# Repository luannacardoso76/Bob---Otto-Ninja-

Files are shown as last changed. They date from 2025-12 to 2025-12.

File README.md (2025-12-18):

# Bob---Otto-Ninja-
Projeto acadêmico do Robô Otto Ninja Humanoide “Bob”, desenvolvido na disciplina Informática Aplicada à Engenharia. O trabalho envolve modelagem com Redes de Petri, impressão 3D, montagem mecânica, integração eletrônica com Arduino Nano e programação embarcada para controle de movimentos e sensores.

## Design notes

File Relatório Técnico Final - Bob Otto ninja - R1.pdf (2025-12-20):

UNIVERSIDADE DO ESTADO DA BAHIA - UNEB DEPARTAMENTO DE CIÊNCIAS EXATAS E DA TERRA I COLEGIADO DE ENGENHARIA DE PRODUÇÃO CIVIL

FELIPE DIAS CAVALCANTE DO NASCIMENTO LUANNA CARDOSO DOS ANJOS

RELATÓRIO TÉCNICO – DESENVOLVIMENTO DO ROBÔ OTTO NINJA HUMANOIDE

SALVADOR - BAHIA
2025

FELIPE DIAS CAVALCANTE DO NASCIMENTO LUANNA CARDOSO DOS ANJOS

RELATÓRIO TÉCNICO – DESENVOLVIMENTO DO ROBÔ OTTO NINJA HUMANOIDE

Relatório Técnico apresentado como critério de avaliação da disciplina Informática Aplicada a Engenharia do curso de Engenharia de Produção Civil da Universidade do Estado da Bahia - UNEB.

Prof. Orientador: Robson Marinho da Silva

SALVADOR - BAHIA
2025

### 1. INTRODUÇÃO

O presente relatório técnico apresenta o desenvolvimento do Robô Otto DIY Ninja Humanoide, denominado “Bob”, realizado no âmbito da disciplina Informática Aplicada à Engenharia, do curso de Engenharia de Produção Civil da Universidade do Estado da Bahia (UNEB). O projeto teve como objetivo integrar conhecimentos de programação, eletrônica básica, modelagem computacional, impressão 3D e gerenciamento de projetos, por meio da prototipagem de um sistema mecatrônico.
O desenvolvimento iniciou-se com a modelagem do comportamento do robô utilizando Redes de Petri simples e compostas, que possibilitaram o planejamento lógico das ações e a definição da arquitetura de controle do sistema. Em seguida, foram realizadas a definição da lista de materiais, a impressão 3D das peças estruturais e a montagem mecânica e elétrica, etapa que demandou ajustes iterativos e adaptações em função das características dos componentes disponíveis.
Por fim, efetuou-se a programação e integração dos subsistemas, envolvendo o controle dos servomotores, a leitura do sensor ultrassônico e a utilização do display para interação visual. Durante essa fase, desafios técnicos, como a substituição de uma placa controladora defeituosa, contribuíram para o desenvolvimento de competências relacionadas à organização, diagnóstico técnico e resolução de problemas, consolidando os objetivos propostos pela disciplina.
2. MODELAGEM DO ROBÔ UTILIZANDO REDES DE PETRI

A primeira etapa do projeto consistiu no desenvolvimento de uma Rede de Petri simples, que evoluiu para uma Rede de Petri composta (colorida), utilizando os softwares HPSIM e CPN Tools. Essas modelagens tiveram como finalidade representar, de forma lógica e estruturada, o comportamento e os movimentos principais do robô.

### 2.1. Rede de Petri Simples

A Rede de Petri simples permitiu mapear:
- Os estados fundamentais do robô (ligado, executando, repouso);
- As transições referentes a movimentos básicos (andar, girar, acenar, mostrar expressões);
- A lógica de alternância entre ações;
- O mecanismo de exclusão mútua (lugar busy), garantindo que apenas uma ação fosse executada por vez.
Esta modelagem facilitou a identificação de cenários de teste e a previsão de situações de bloqueio (deadlock) e condições de corrida, orientando ajustes posteriores no projeto físico e no código de controle.

### 2.2. Rede de Petri Composta (Colorida)

A etapa seguinte consistiu na construção de uma Rede de Petri colorida, que representa tokens com informações (cores) como tipo de comando, parâmetros e estados. A modelagem colorida possibilitou:

- Compactar várias situações (ex.: diferentes comandos) em uma mesma estrutura de transição;
- Simular cenários com parâmetros (velocidade, duração, prioridade);
- Verificar lógica de interação entre subsistemas (pernas, rodas, braços, display e sensor de obstáculo).
A modelagem por Redes de Petri, tanto simples quanto colorida, foi relevante para antecipar o comportamento do robô, definindo critérios de sucesso para a implementação e testes.
3. LISTA DE MATERIAIS DO PROJETO

Após a fase de modelagem, elaborou-se a lista de materiais necessária para a montagem do protótipo. A lista incluiu itens eletrônicos, mecânicos e de fixação, bem como as peças a serem impressas em 3D. Entre os componentes principais destacam-se:
- 5 Servomotores de 180°;
- 2 Servomotores de 360°;
- 1 Sensor ultrassônico HC-SR04;
- 1 Tela OLED 0.96" I2C 128x64 (display);
- 1 Placa controladora Shield associada ao Arduino Nano;
- 1 Bateria recarregável de 7,4V;
- Cabos Dupont, conectores e parafusos;
- 2 Capacitores Ketuo 16V;
- Peças estruturais impressas em 3D (lista detalhada na Seção 4).
Ressalta-se que alguns componentes diferiram das especificações originais do projeto Otto DIY, em função da disponibilidade de materiais fornecidos, exigindo adaptações durante o desenvolvimento.

### 4. IMPRESSÃO 3D DAS PEÇAS ESTRUTURAIS

A estrutura mecânica do robô foi produzida por meio de impressão 3D, processo que demandou diversas iterações até a obtenção de peças com qualidade dimensional e acabamento adequados.

### 4.1. Peças Impressas

Foram impressas as seguintes peças:
- Tampa preta para cabeça;
- Base da cabeça;
- Espada azul;
- 2 × Ombros;
- 2 × Braços;
- Tornozelo esquerdo;
- Tornozelo direito;
- Base preta;
- 2 × Pés;
- Parte inferior interna;

- Pernas;
- Tampa inicial;
- Tampa ultrassônica para o sensor;
- Faixa azul.

### 4.2. Processo e ajustes

A impressão das peças durou várias semanas. Algumas peças foram reimpressas devido a falhas de acabamento ou dimensionais. Foi necessário ajustar modelos no software Autodesk Fusion 360, entre eles:
- Redimensionamento e reposicionamento da abertura frontal do corpo para acomodar a matriz de LEDs (a matriz adquirida apresentou dimensões diferentes do modelo original);
- Correções de encaixe nas articulações (ombros e tornozelos);
- Inclusão de características estéticas e identificação (nome dos integrantes, nome do orientador, ano e mês), que foram incorporadas ao modelo final.

### 5. MONTAGEM MECÂNICA E INSTALAÇÃO DOS COMPONENTES

Finalizadas as impressões e os ajustes, procedeu-se à montagem mecânica e à instalação dos atuadores e sensores.

### 5.1. Instalação de servos

Os servos foram instalados conforme a arquitetura prevista:
- Pernas: em cada perna foi instalado um servo de 180° e um servo de 360°;
- Braços: um servo de 360º por braço;
- Cabeça: um servo de 360° (para movimentação da cabeça) e sensor ultrassônico HC-SR04 montado na tampa frontal;
- Posições físicas dos servos e referências de portas na shield.

### 5.2. Bateria e alimentação

A bateria utilizada foi do tipo: Bateria recarregável 7,4V, instalada na cavidade do corpo. A alimentação é gerenciada por um capacitor conforme especificações da lista de materiais, garantindo 5V para os servos e 3.3V/5V para a placa controladora conforme necessidade.

### 5.3. Placa controladora e conexões

O robô utilizou a combinação Shield e Arduino Nano.

### 5.4. Conexões e Cabeamento

Os componentes foram conectados às portas apropriadas da Shield:
- Servos das pernas
o Direita → posição: 3
o Esquerda → posição: 2
- Servos dos pés
o Direita → posição: 5
o Esquerda → posição: 4

- Servos dos braços
o Direita → posição: 7
o Esquerda → posição: 6
- Servo da cabeça → posição: 10
- Sensor ultrassônico
o Saída: VCC → Cabo: vermelho → posição: 9V o Saída: TRIG → Cabo: preto → posição: 8S
o Saída: ECHO → Cabo: branco → posição: 9S o Saída: GND → Cabo: cinza → posição: 8G
- Display (tela OLED)
o Saída: GND → Cabo: verde → posição: A4G o Saída: VDD → Cabo: amarelo → posição: A4V o Saída: SCK → Cabo: salmão → posição: A5S o Saída: SDA → Cabo: vermelho → posição: A4S
- Bateria
o Cabo: vermelho → posição: VIN
o Cabo: preto → posição: GND
- Capacitor
o 5/Cabo: azul → posição: 0G
o Cabo: amarelo → posição: 0V

### 6. PROGRAMAÇÃO E INTEGRAÇÃO

Com os componentes integrados, iniciou-se a preparação do ambiente de desenvolvimento e a configuração da placa no Arduino IDE. As etapas realizadas até o ponto atual incluem:
- Instalação de bibliotecas para servos, sensor ultrassônico, e para o controlador da matriz;
- Configuração da placa e da porta serial;
- Planejamento da arquitetura de software baseada nas Redes de Petri desenvolvidas. Nessa etapa, foi identificado que a placa Arduino Nano inicialmente utilizada apresentava indícios de falha, possivelmente decorrente de dano físico no circuito, conforme evidenciado pelo furo observado na placa (Figura 1). Tal condição impossibilitou a comunicação adequada entre o computador e o microcontrolador, inviabilizando o carregamento do firmware e a execução dos testes iniciais.

Figura 1 - Arduino Nano com furo sugerindo placa queimada

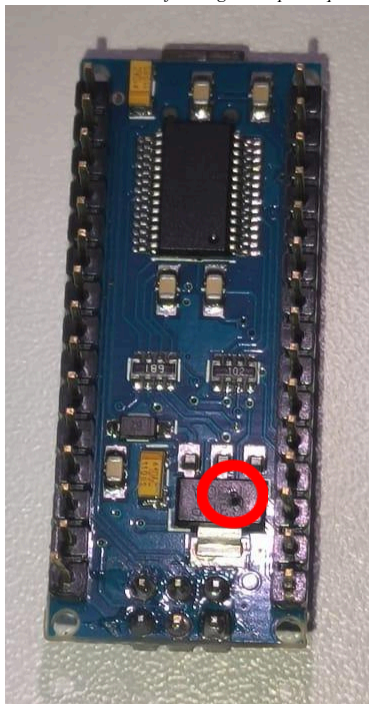
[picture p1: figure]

Fonte: O autor (2025)
Diante desse diagnóstico, tornou-se necessária a aquisição de um novo Arduino Nano, permitindo a retomada das atividades de programação. Após a substituição da placa, foi possível configurar corretamente o ambiente no Arduino IDE, estabelecer comunicação serial e iniciar a implementação do código responsável pelo controle dos servomotores, leitura do sensor ultrassônico e acionamento do display.

### 7. GERENCIAMENTO DO PROJETO

O acompanhamento e a organização do projeto foram realizados por meio da ferramenta Trello, utilizada para:
- Criação de cartões de tarefas (impressão 3D, montagem, programação, testes);
- Atribuição de responsabilidades entre os integrantes;
- Registro de progresso e impedimentos;
- Armazenamento de registros de iteração (reimpressões, ajustes de modelo) e fotos das peças.
O uso do Trello permitiu manter rastreabilidade das atividades, priorizar tarefas e documentar decisões durante todo o desenvolvimento.

### 8. DOCUMENTAÇÃO DO PROJETO

A documentação do projeto foi elaborada de forma contínua ao longo de todas as etapas de desenvolvimento do Robô Otto Ninja Humanoide. Foram produzidos registros técnicos que contemplam a modelagem do sistema por meio de Redes de Petri, a lista de materiais, os arquivos de modelagem e impressão 3D, registros fotográficos do processo de fabricação e montagem, esquemas de ligação elétrica e versões sucessivas do código-fonte desenvolvido. Além disso, foi criado um repositório no GitHub (https://github.com/luannacardoso76/Bob---Otto-Ninja-.git) com a finalidade de centralizar e preservar todos os arquivos digitais do projeto, incluindo códigos de programação, diagramas, modelos tridimensionais e documentos textuais. Essa prática contribuiu para a organização, rastreabilidade e versionamento das informações, possibilitando maior transparência, reprodutibilidade do projeto e facilidade para futuras melhorias. O uso dessa plataforma também está alinhado às boas práticas de engenharia e desenvolvimento tecnológico, especialmente no que se refere ao trabalho colaborativo e à gestão de versões.

### 9. CONSIDERAÇÕES FINAIS

O desenvolvimento do Robô Otto DIY Ninja Humanoide proporcionou aos integrantes uma experiência prática e integrada, envolvendo conceitos de programação, eletrônica, modelagem computacional, impressão 3D e gerenciamento de projetos. A utilização das Redes de Petri mostrou-se uma ferramenta eficiente para o planejamento lógico do comportamento do robô, auxiliando na organização das ações e na redução de falhas durante a integração entre os subsistemas.
As etapas de impressão 3D e montagem mecânica evidenciaram a importância do processo iterativo de prototipagem, uma vez que ajustes sucessivos foram necessários até alcançar um resultado funcional e esteticamente satisfatório. No âmbito da programação, a identificação e substituição da placa Arduino Nano defeituosa representaram um desafio relevante, reforçando a necessidade de diagnóstico técnico, tomada de decisão e adaptação frente a imprevistos, situações comuns em projetos de engenharia.
De modo geral, os objetivos propostos pela disciplina foram plenamente atingidos, permitindo a consolidação dos conhecimentos teóricos por meio de sua aplicação prática. O projeto demonstrou o potencial do Robô Otto como plataforma educacional para o aprendizado de automação, programação e sistemas mecatrônicos, além de contribuir para o desenvolvimento de competências como trabalho em equipe, organização, planejamento e resolução de problemas.

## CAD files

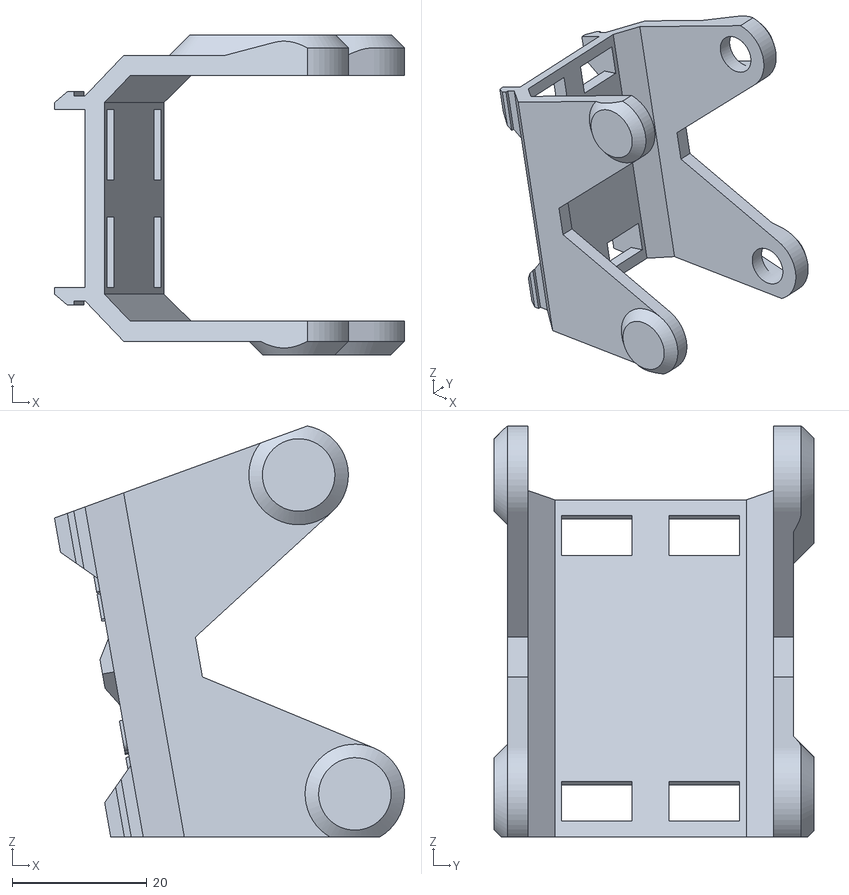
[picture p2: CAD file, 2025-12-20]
Legs - Otto DIY_Ninja_LEGS.stl
51.9 x 47.4 x 60.9

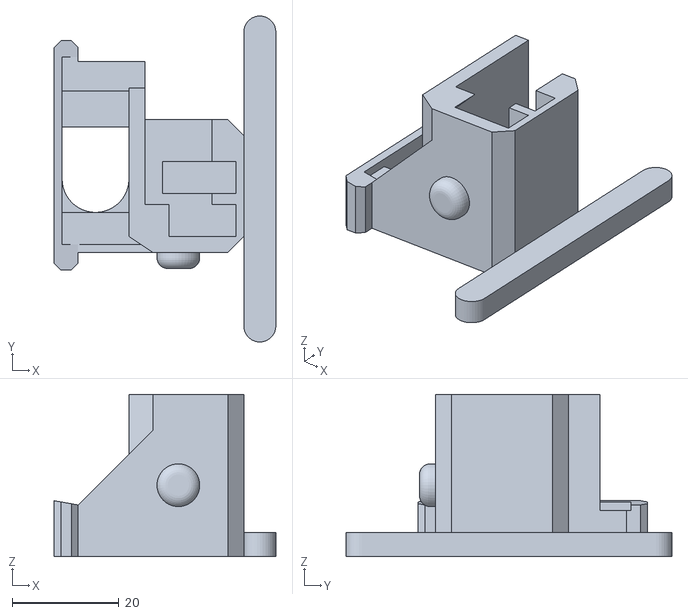
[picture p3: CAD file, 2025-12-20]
Perna direita - Otto DIY_Ninja_Leg Right.stl
41.5 x 61.0 x 30.4

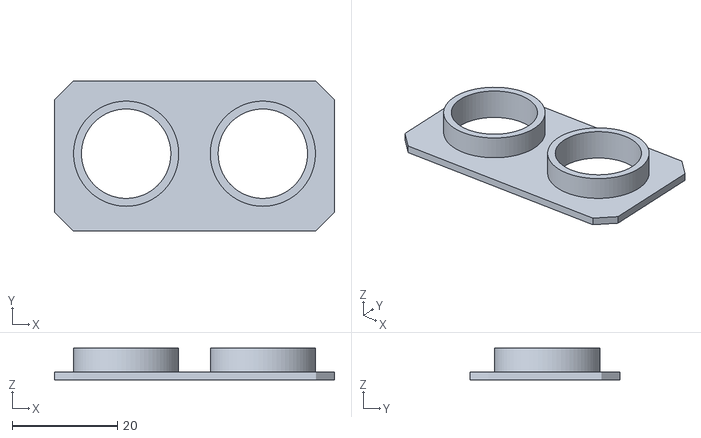
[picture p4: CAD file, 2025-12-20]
Olho - Otto DIY_Ninja_PLATE ULTRASONIC.stl
53.3 x 28.5 x 6.00

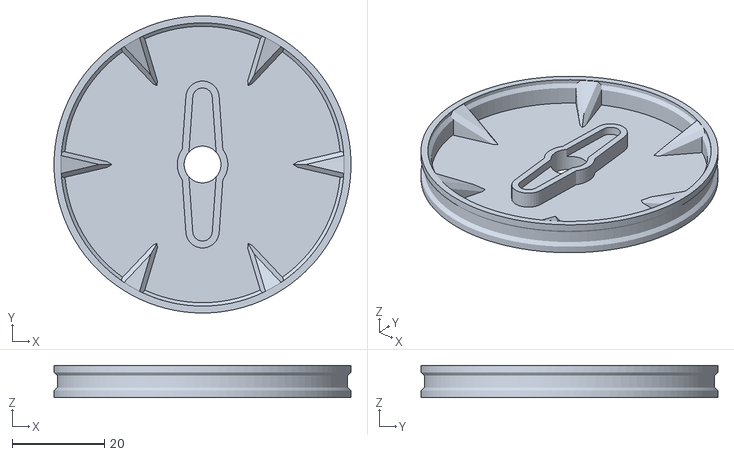
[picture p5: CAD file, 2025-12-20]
Pés x2 - Otto DIY_Ninja_FootWheels x2.stl
64.5 x 64.5 x 7.00

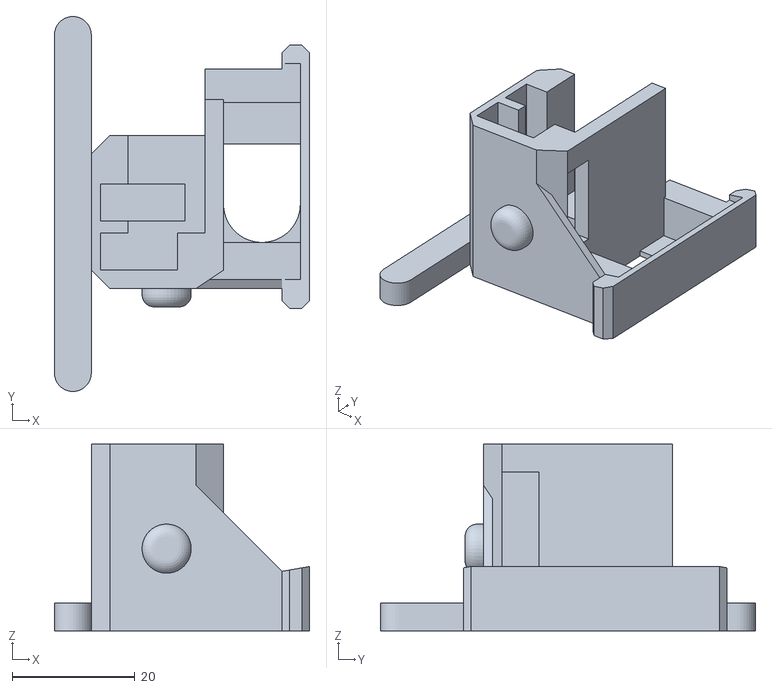
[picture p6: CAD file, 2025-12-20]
Perna esquerda - Otto DIY_Ninja_Leg Left.stl
41.5 x 61.0 x 30.4

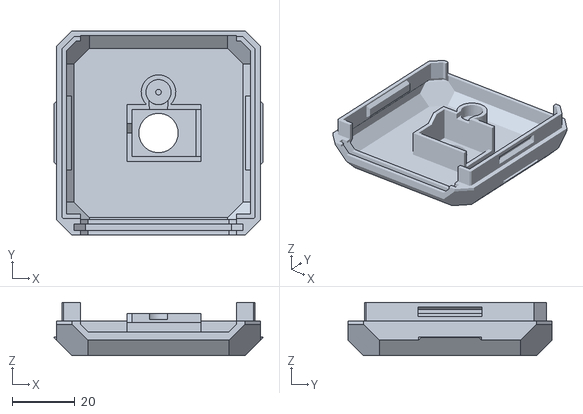
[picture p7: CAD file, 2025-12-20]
Tampa - Otto DIY_Ninja_LID.stl
66.5 x 65.0 x 17.0

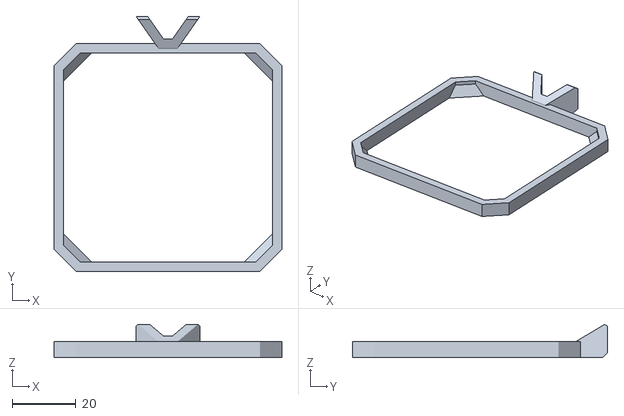
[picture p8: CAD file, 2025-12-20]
Faixa - Otto DIY_Ninja_BAND.stl
71.5 x 80.0 x 10.4

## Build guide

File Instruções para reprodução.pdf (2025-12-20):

UNIVERSIDADE DO ESTADO DA BAHIA - UNEB DEPARTAMENTO DE CIÊNCIAS EXATAS E DA TERRA I COLEGIADO DE ENGENHARIA DE PRODUÇÃO CIVIL

FELIPE DIAS CAVALCANTE DO NASCIMENTO LUANNA CARDOSO DOS ANJOS

INSTRUÇÕES PARA REPRODUÇÃO DO PROJETO – ROBÔ OTTO NINJA HUMANOIDE

SALVADOR - BAHIA
2025

A reprodução do Robô Otto DIY Ninja Humanoide requer a execução sequencial de etapas que envolvem preparação de materiais, fabricação das peças estruturais, montagem mecânica e elétrica, e programação do sistema. Recomenda-se seguir rigorosamente a ordem apresentada a seguir, a fim de garantir o correto funcionamento do protótipo.

### 1. LISTA DE MATERIAIS

- 5 Servomotores de 180°;
- 2 Servomotores de 360°;
- 1 Sensor ultrassônico HC-SR04;
- 1 Tela OLED 0.96" I2C 128x64 (display);
- 1 Placa controladora Shield associada ao Arduino Nano;
- 1 Bateria recarregável de 7,4V;
- Cabos Dupont, conectores e parafusos;
- 2 Capacitores Ketuo 16V;
- Peças estruturais impressas em 3D (lista detalhada na Seção 4).

### 2. PREPARAÇÃO DOS MATERIAIS

Inicialmente, deve-se providenciar todos os componentes eletrônicos, mecânicos e de fixação descritos na lista de materiais. É fundamental verificar previamente a compatibilidade entre os componentes disponíveis e os modelos utilizados, especialmente no que se refere à placa controladora, display e servomotores, uma vez que eventuais diferenças dimensionais podem exigir ajustes nos modelos impressos.
Também é necessário dispor de:
- Impressora 3D devidamente calibrada;
- Ambiente de desenvolvimento Arduino IDE ou OttoBlocky instalado e atualizado;
- Bibliotecas necessárias para controle de servos, display OLED e sensor ultrassônico ou código fonte desenvolvido para o projeto.

### 3. IMPRESSÃO 3D DAS PEÇAS

Com os arquivos STL disponíveis, deve-se proceder à impressão das peças estruturais do robô, respeitando as orientações de material, orientação e preenchimento recomendadas. Após a impressão, as peças devem ser inspecionadas quanto a falhas de acabamento, empenamento ou incompatibilidade dimensional.

Caso necessário, ajustes podem ser realizados nos arquivos STL utilizando softwares de modelagem tridimensional, como o Autodesk Fusion 360, especialmente para adequação aos componentes disponíveis.

### 4. MONTAGEM MECÂNICA

A montagem mecânica deve iniciar-se pela fixação dos servomotores nas pernas, pés, braços e cabeça, garantindo o correto posicionamento e alinhamento dos eixos. Em seguida, as peças estruturais devem ser montadas conforme a hierarquia do projeto (pernas, base, corpo, braços e cabeça), utilizando parafusos adequados e evitando esforços excessivos que possam danificar as peças impressas.

É recomendável realizar a calibração inicial dos servos antes do fechamento completo da estrutura, assegurando que todos estejam posicionados em seus ângulos de referência.

### 5. INSTALAÇÃO ELÉTRICA E ELETRÔNICA

Após a montagem mecânica, procede-se à instalação da placa controladora, da bateria, do sensor ultrassônico, do display OLED e dos demais componentes eletrônicos. As conexões devem ser realizadas conforme o esquema de cabeamento definido no projeto, respeitando polaridades, portas e níveis de tensão.
Os componentes devem ser conectados às portas apropriadas da Shield:
- Servos das pernas
o Direita → posição: 3
o Esquerda → posição: 2
- Servos dos pés
o Direita → posição: 5
o Esquerda → posição: 4
- Servos dos braços
o Direita → posição: 7
o Esquerda → posição: 6
- Servo da cabeça → posição: 10
- Sensor ultrassônico
o Saída: VCC → Cabo: vermelho → posição: 9V o Saída: TRIG → Cabo: preto → posição: 8S
o Saída: ECHO → Cabo: branco → posição: 9S o Saída: GND → Cabo: cinza → posição: 8G
- Display (tela OLED)
o Saída: GND → Cabo: verde → posição: A4G o Saída: VDD → Cabo: amarelo → posição: A4V o Saída: SCK → Cabo: salmão → posição: A5S o Saída: SDA → Cabo: vermelho → posição: A4S
- Bateria
o Cabo: vermelho → posição: VIN
o Cabo: preto → posição: GND
- Capacitor
o 5/Cabo: azul → posição: 0G
o Cabo: amarelo → posição: 0V
Deve-se conferir cuidadosamente todas as ligações antes da energização do sistema, a fim de evitar curtos-circuitos ou danos aos componentes.

### 6. PROGRAMAÇÃO E TESTES

Com o hardware montado, o código-fonte deve ser carregado na placa controladora por meio da Arduino IDE ou OttoBlocky. Após o carregamento, recomenda-se realizar testes individuais dos subsistemas conforme códigos criados (movimento das pernas, braços, cabeça, leitura do sensor e funcionamento do display), antes da execução completa da sequência de ações programadas.
Caso sejam identificados comportamentos inadequados, ajustes podem ser feitos nos parâmetros de tempo, ângulos dos servos ou lógica de controle.

### 7. DOCUMENTAÇÃO

Com o objetivo de garantir transparência, organização e reprodutibilidade do projeto, todos os arquivos desenvolvidos ao longo do trabalho foram disponibilizados em um repositório na plataforma GitHub. Nesse repositório encontram-se reunidos os principais materiais digitais do projeto, incluindo o código-fonte utilizado na programação do robô, os arquivos STL para impressão 3D das peças estruturais, os diagramas de Redes de Petri, bem como documentos complementares relacionados ao desenvolvimento e à documentação técnica.
A disponibilização dos arquivos em ambiente de versionamento possibilita o acesso público ao projeto, facilita eventuais adaptações ou melhorias futuras e está alinhada às boas práticas de engenharia e desenvolvimento tecnológico. Dessa forma, qualquer interessado pode reproduzir o protótipo, analisar as soluções adotadas ou utilizá-las como base para novos projetos acadêmicos ou educacionais.

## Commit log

2025-12-18 Add files via upload
    Arquivo referente à primeira apresentação do projeto Robô Otto Ninja Humanoide “Bob”,
    realizada na disciplina Informática Aplicada à Engenharia.
    O material apresenta a proposta inicial, modelagem em Rede de Petri e planejamento do projeto.
2025-12-18 Add files via upload
    Modelagem da rede de Petri simples referente ao crédito 1 da disciplina
2025-12-18 Add files via upload
    O material apresenta a proposta inicial, modelagem em Rede de Petri colorida e planejamento do projeto.
    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
2025-12-20 Rename Modelagem otto ninja _v3.hps to Rede de Petri simples
2025-12-20 Rename Redee de Petri simples to Rede de Petri simples
2025-12-20 Rename Rede de Petri simples to Rede de Petri simples - HPSim
2025-12-20 Rename Modelagem otto ninja _v3.pdf to Rede de Petri simples - pdf
2025-12-20 Arquivos para impressão
    [Faixa - Otto DIY_Ninja_BAND.stl, Legs - Otto DIY_Ninja_LEGS.stl, Olho - Otto DIY_Ninja_PLATE ULTRASONIC.stl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]
2025-12-20 Código - Sensor Ultrassônico
2025-12-20 Bibliotecas para o display
2025-12-20 Código - Ninja sem display e sem sensor
2025-12-20 Relatório Técnico de Desenvolvimento - Robô Otto
2025-12-20 Instruções para reprodução do Robo Otto Ninja
